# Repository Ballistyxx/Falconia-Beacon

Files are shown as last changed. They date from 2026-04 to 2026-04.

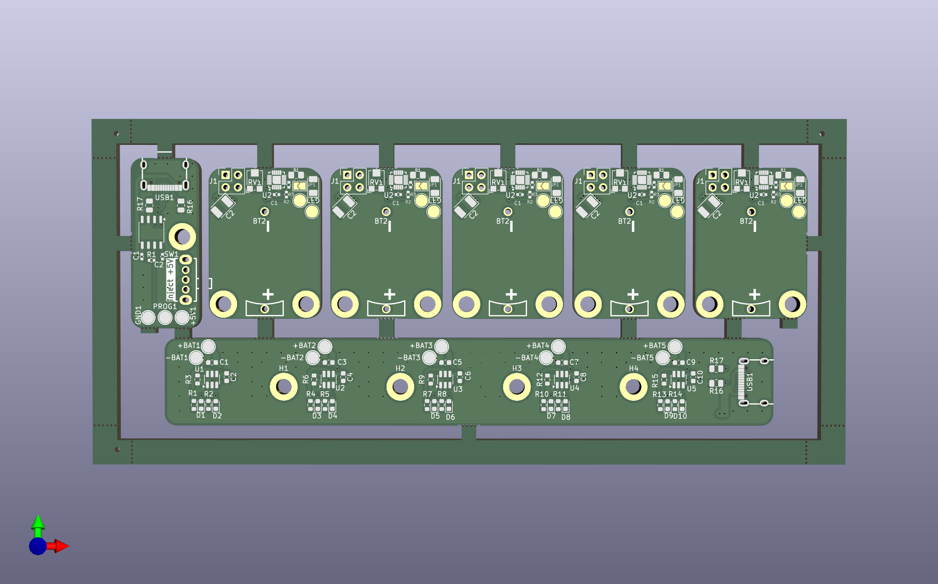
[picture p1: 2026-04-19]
PCB/Datasheets/Panel.png

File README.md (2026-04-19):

# Falconia Beacon

Falconia Beacon is an ATTINY816-based, CR2032-powered LED beacon board used to make the Falconia rover visible to the SMCS Pi-in-the-sky satellite.

## What It Does

- Blinks onboard LEDs so the satellite can detect the rover location.
- Uses a potentiometer to enable or disable the blinking program.
- Supports I2C control at address `0x42`.

## Project Layout

- `PCB/`  
  Hardware design and manufacturing assets:
  - KiCad schematic and PCB files
  - 3D models and custom footprints/symbol libraries
  - Panelization and production outputs

- `src/`  
  Firmware source flashed to the board by default:
  - Main beacon firmware and related examples
  - Build files (Makefile)

## Hardware Summary

- MCU: Microchip ATTINY816
- Power: CR2032 coin cell
- Interface: I2C (address `0x42`)
- User control: Potentiometer (blink program on/off)

## Firmware

The default board firmware lives in `src/` and is intended to be the code programmed onto production boards unless otherwise noted.

Typical workflow:

1. Build firmware from the `src/` directory.
2. Flash using your ATTINY816 programming setup.
3. Validate LED blink behavior and I2C response at address `0x42`.

## Notes

- Hardware and firmware are versioned together in this repository.
- For board-level updates, start in `PCB/`.
- For behavior/protocol updates, start in `src/`.

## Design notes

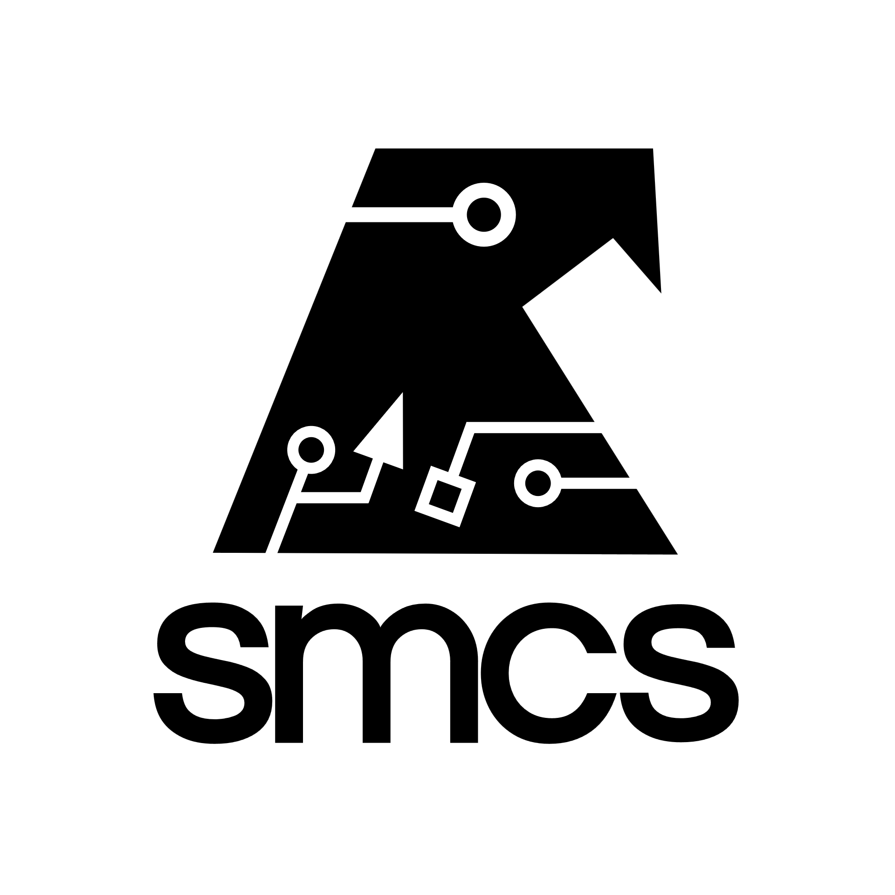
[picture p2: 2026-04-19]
PCB/SMCS.png

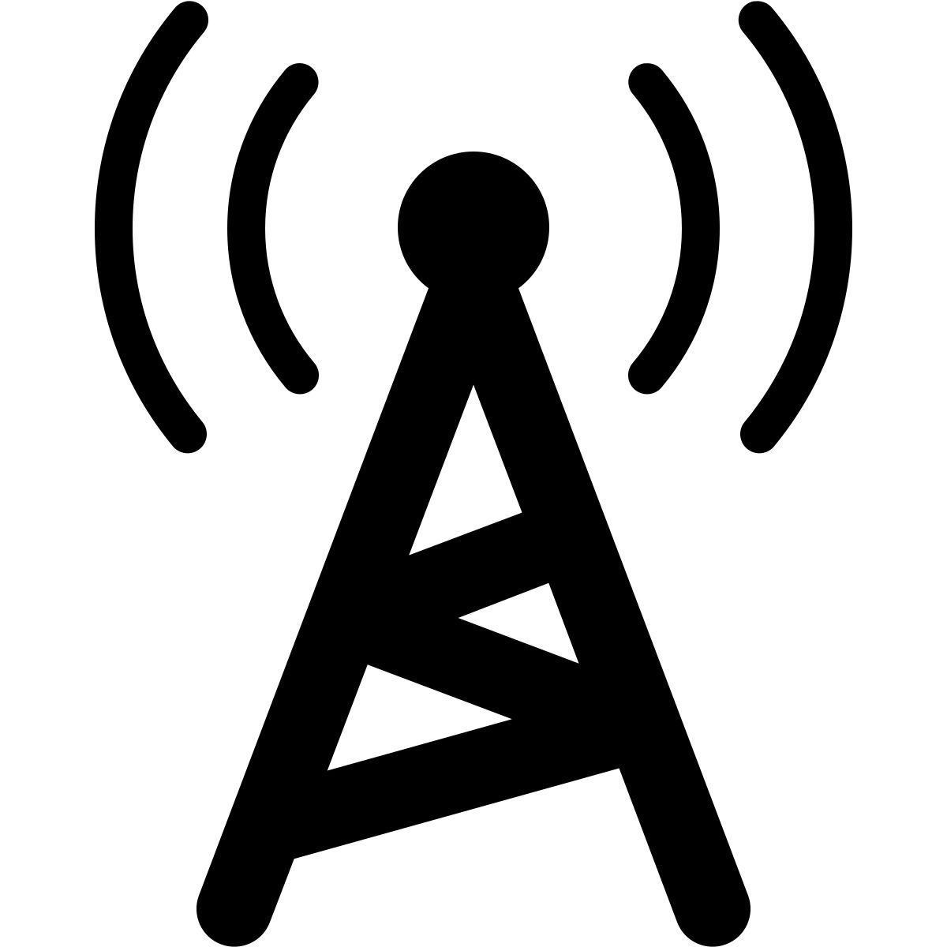
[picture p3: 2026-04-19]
PCB/radio-tower.jpg

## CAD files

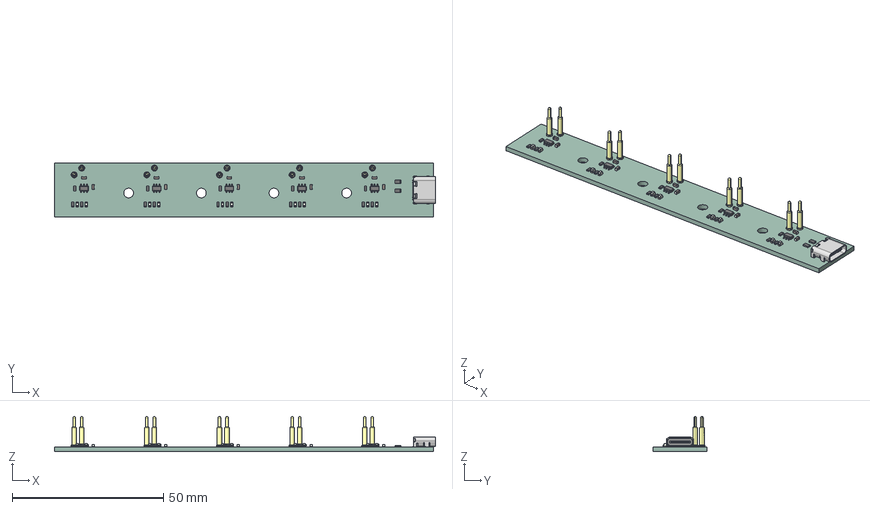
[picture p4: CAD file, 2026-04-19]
PCB/Charger/charger.step
125.9 x 18.0 x 11.6 mm
TSOT-23-6 x 5
SMD-1_BD2.0-H10.0 x 10
LED_0603_1608Metric x 10
R_0603_1608Metric x 15
C_0603_1608Metric x 10
R_0805_2012Metric x 2
USB-C-SMD_TYPE-C-6PIN-2MD-073
charger_PCB

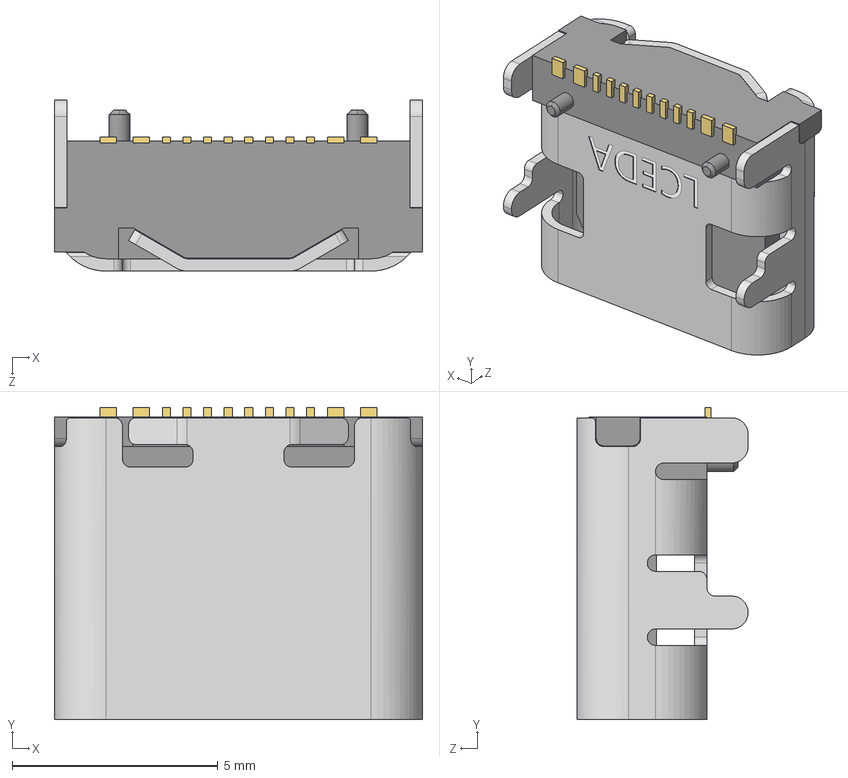
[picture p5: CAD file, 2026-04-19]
PCB/Charger/jlcpcb_lib/3dmodels/USB-C-SMD_TYPE-C-6PIN-2MD-073.step
8.94 x 7.58 x 4.16 mm

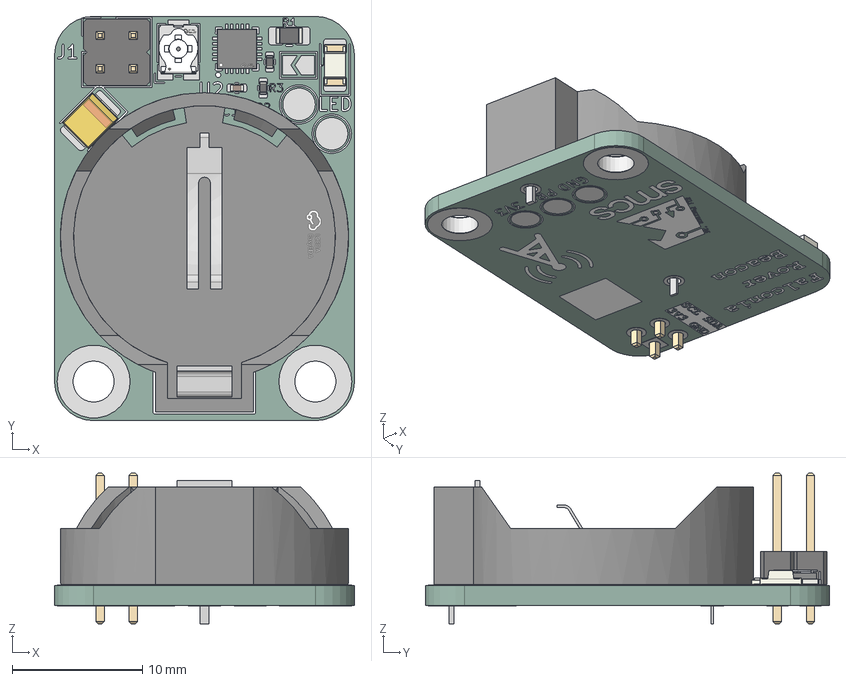
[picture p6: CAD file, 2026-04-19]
PCB/Falconia-Beacon/Falconia-Beacon.step
23.0 x 31.0 x 11.5 mm
CP_EIA-3528-21_Kemet-B
R_0805_2012Metric
UQFN-20_L3.0-W3.0-P0.40-BL-EP1.7
C_0402_1005Metric
BAT-TH_BS-02-A1AJ010
R_0402_1005Metric x 2
PinHeader_2x02_P2.54mm_Vertical
RES-ADJ-SMD_3P-L3.0-W3.8-P1.75-BR
LED_1206_3216Metric
Falconia-Beacon_pad
Falconia-Beacon_silkscreen x 2
Falconia-Beacon_PCB

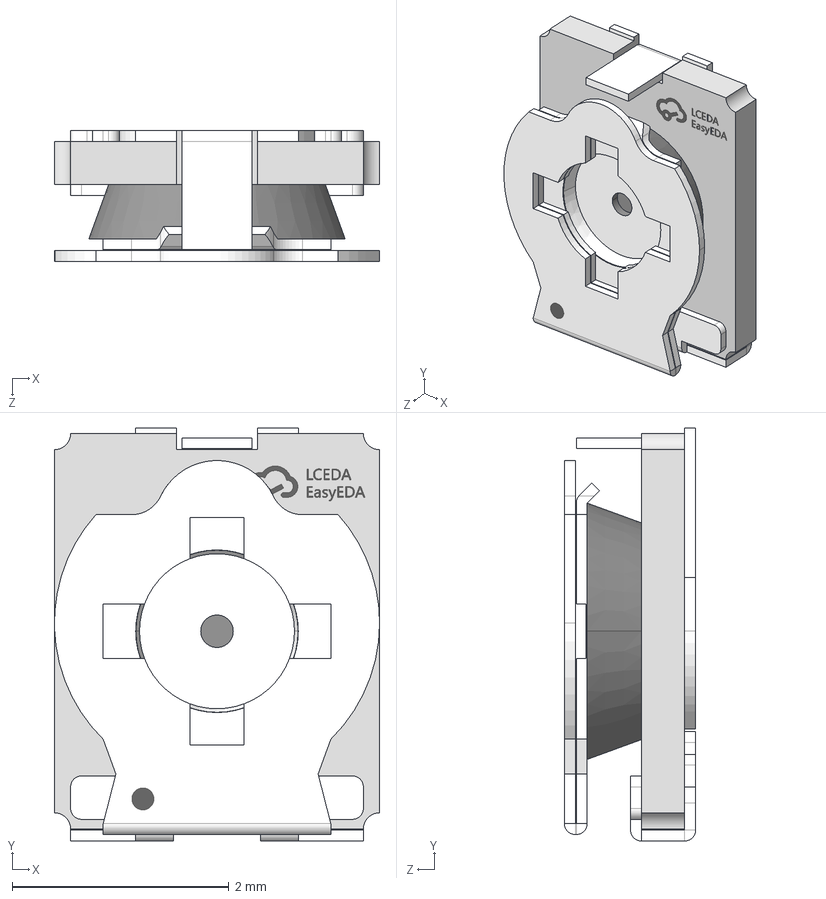
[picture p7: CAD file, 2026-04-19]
PCB/Falconia-Beacon/jlcpcb_lib/3dmodels/RES-ADJ-SMD_3P-L3.0-W3.8-P1.75-BR.step
3.00 x 3.81 x 1.21 mm

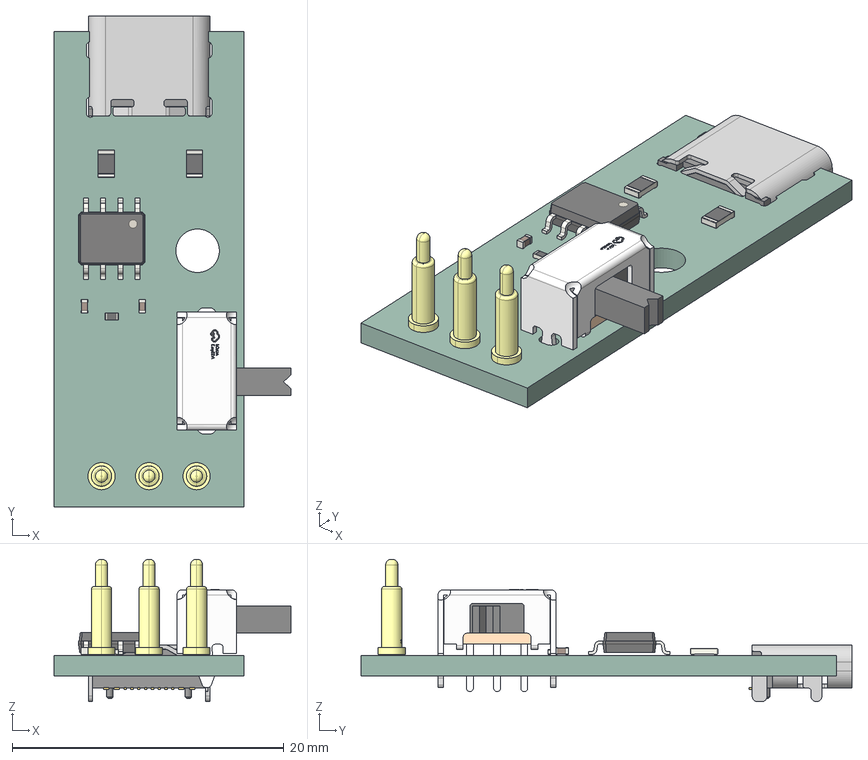
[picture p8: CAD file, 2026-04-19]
PCB/Programmer/programmer.step
17.5 x 36.1 x 10.5 mm
R_0402_1005Metric
BAT-SMD_BD2.0-2P-2.54PH-7.0H x 3
SW-TH_SK12D07VG3
R_0805_2012Metric x 2
C_0402_1005Metric x 2
JEITA_SOIC-8_3.9x4.9mm_P1.27mm
USB-C-SMD_TYPE-C-6PIN-2MD-073
programmer_PCB

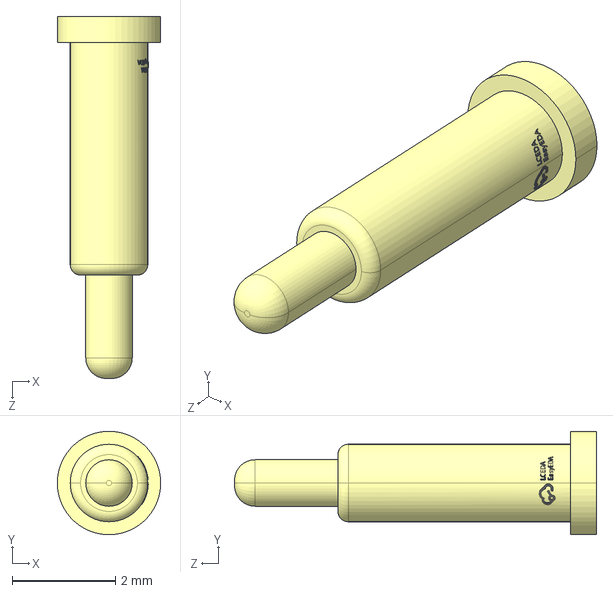
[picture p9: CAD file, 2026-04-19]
PCB/Charger/jlcpcb_lib/3dmodels/BAT-SMD_BD2.0-2P-2.54PH-7.0H.step
2.00 x 2.00 x 7.00 mm

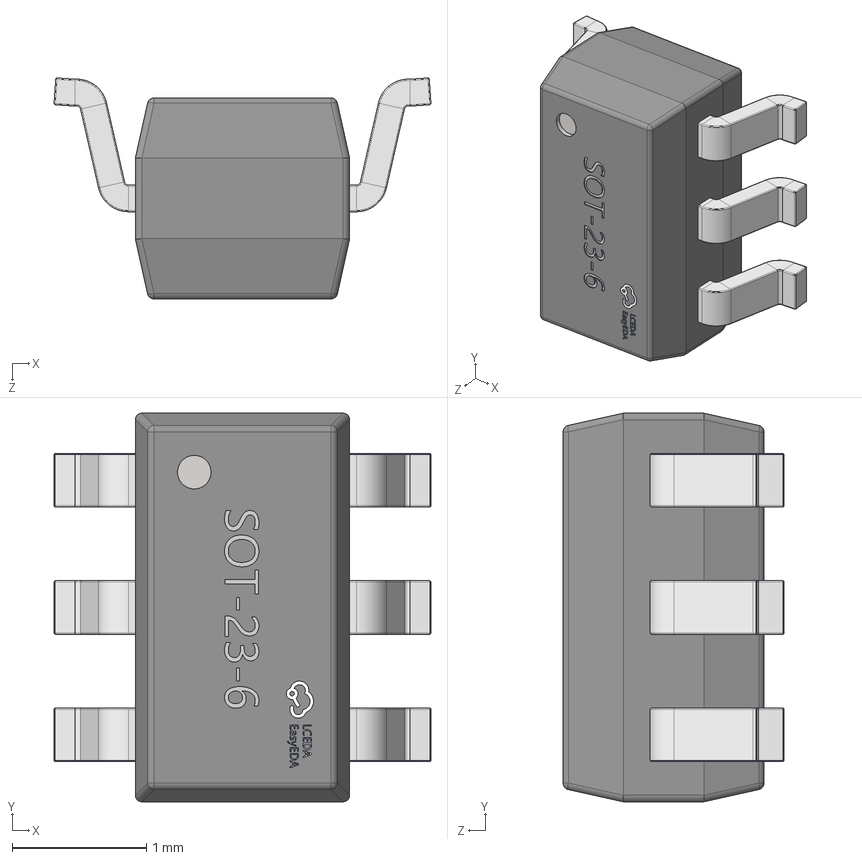
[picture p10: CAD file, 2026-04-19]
PCB/Falconia-Beacon/jlcpcb_lib/3dmodels/SOT-23-6_L2.9-W1.6-P0.95-LS2.8-BL.step
2.81 x 2.90 x 1.65 mm

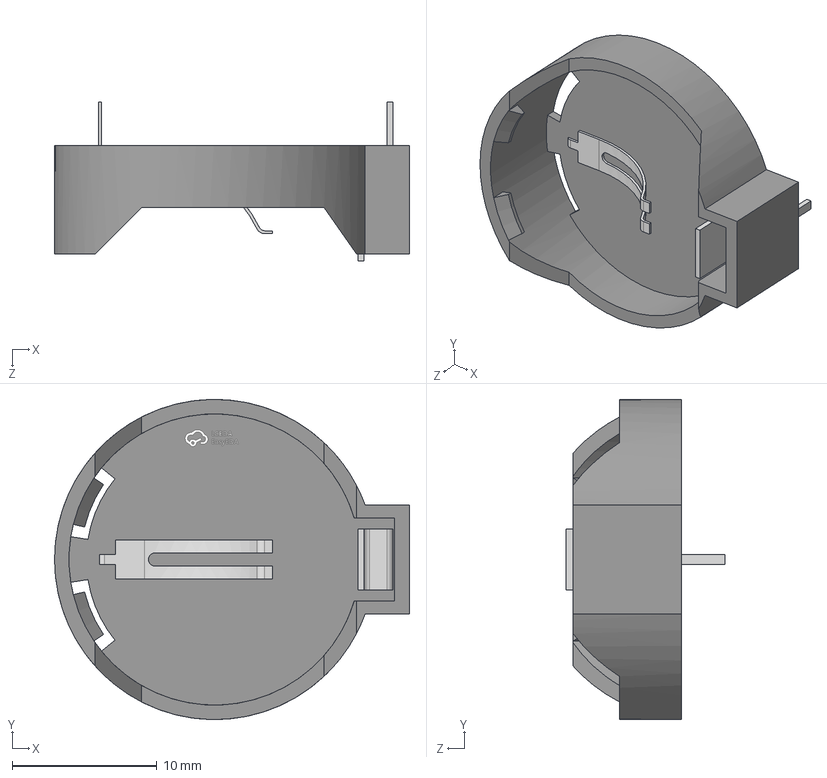
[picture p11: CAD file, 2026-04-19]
PCB/Falconia-Beacon/jlcpcb_lib/3dmodels/BAT-TH_BS-02-A1AJ010.step
24.5 x 22.1 x 11.0 mm

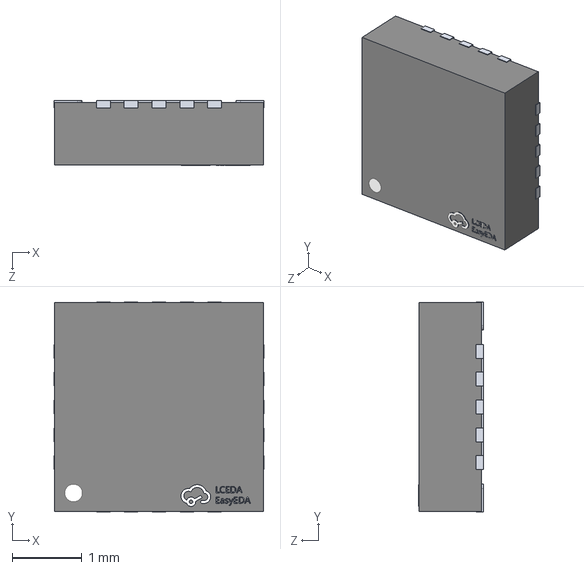
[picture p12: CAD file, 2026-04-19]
PCB/Falconia-Beacon/jlcpcb_lib/3dmodels/UQFN-20_L3.0-W3.0-P0.40-BL-EP1.7.step
3.02 x 3.02 x 0.94 mm

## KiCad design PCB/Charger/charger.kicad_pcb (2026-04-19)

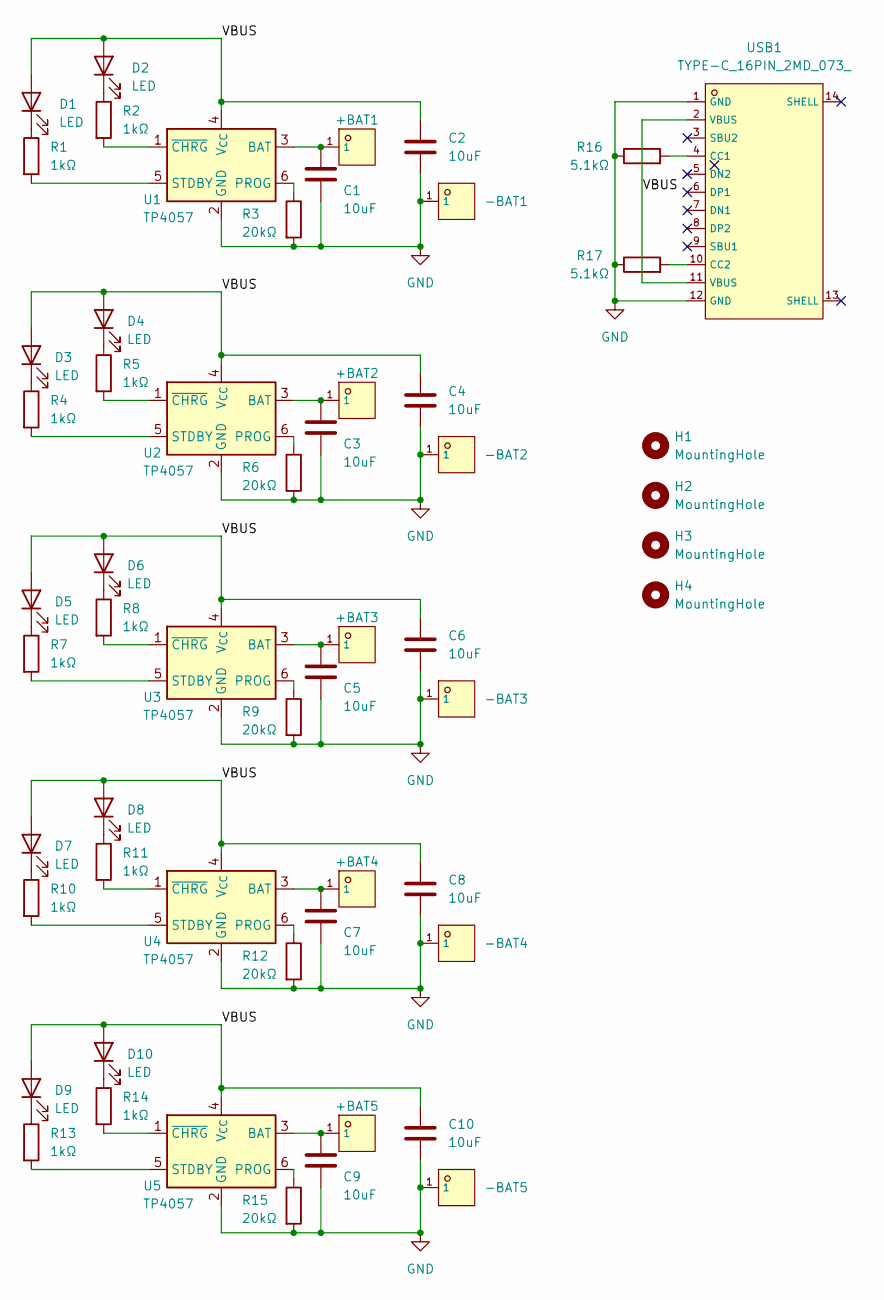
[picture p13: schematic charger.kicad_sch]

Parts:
+BAT1, +BAT2, +BAT3, +BAT4, +BAT5: YTC1P-6030-01; SMD-1_BD2.0-H10.0; LCSC C5221285
-BAT1, -BAT2, -BAT3, -BAT4, -BAT5: YTC1P-6030-01; SMD-1_BD2.0-H10.0; LCSC C5221285
C1, C2, C3, C4, C5, C6, C7, C8, C9, C10: 10uF; C_0603_1608Metric
D1, D2, D3, D4, D5, D6, D7, D8, D9, D10: LED; LED_0603_1608Metric
H1, H2, H3, H4: MountingHole; MountingHole_3.2mm_M3_ISO7380_Pad
R1, R2, R4, R5, R7, R8, R10, R11, R13, R14: 1kΩ; R_0603_1608Metric
R3, R6, R9, R12, R15: 20kΩ; R_0603_1608Metric
R16, R17: 5.1kΩ; R_0805_2012Metric
U1, U2, U3, U4, U5: TP4057; TSOT-23-6
USB1: TYPE-C_16PIN_2MD_073_; USB-C-SMD_TYPE-C-6PIN-2MD-073; LCSC C2765186

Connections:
/VBUS: C2.1, C4.1, C6.1, C8.1, C10.1, D1.2 (A), D2.2 (A), D3.2 (A), D4.2 (A), D5.2 (A), D6.2 (A), D7.2 (A), D8.2 (A), D9.2 (A), D10.2 (A), U1.4 (V_{CC}), U2.4 (V_{CC}), U3.4 (V_{CC}), U4.4 (V_{CC}), U5.4 (V_{CC}), USB1.2 (VBUS), USB1.11 (VBUS)
GND: -BAT1.1, -BAT2.1, -BAT3.1, -BAT4.1, -BAT5.1, C1.2, C2.2, C3.2, C4.2, C5.2, C6.2, C7.2, C8.2, C9.2, C10.2, R3.2, R6.2, R9.2, R12.2, R15.2, R16.1, R17.1, U1.2 (GND), U2.2 (GND), U3.2 (GND), U4.2 (GND), U5.2 (GND), USB1.1 (GND), USB1.12 (GND)
unnamed: D1.1 (K), R1.1
unnamed: D2.1 (K), R2.1
unnamed: D3.1 (K), R4.1
unnamed: D4.1 (K), R5.1
unnamed: D5.1 (K), R7.1
unnamed: D6.1 (K), R8.1
unnamed: D7.1 (K), R10.1
unnamed: D8.1 (K), R11.1
unnamed: D9.1 (K), R13.1
unnamed: D10.1 (K), R14.1
unnamed: +BAT1.1, C1.1, U1.3 (BAT)
unnamed: R3.1, U1.6 (PROG)
unnamed: R1.2, U1.5 (STDBY)
unnamed: R2.2, U1.1 (~CHRG)
unnamed: +BAT2.1, C3.1, U2.3 (BAT)
unnamed: R6.1, U2.6 (PROG)
unnamed: R4.2, U2.5 (STDBY)
unnamed: R5.2, U2.1 (~CHRG)
unnamed: +BAT3.1, C5.1, U3.3 (BAT)
unnamed: R9.1, U3.6 (PROG)
unnamed: R7.2, U3.5 (STDBY)
unnamed: R8.2, U3.1 (~CHRG)
unnamed: +BAT4.1, C7.1, U4.3 (BAT)
unnamed: R12.1, U4.6 (PROG)
unnamed: R10.2, U4.5 (STDBY)
unnamed: R11.2, U4.1 (~CHRG)
unnamed: +BAT5.1, C9.1, U5.3 (BAT)
unnamed: R15.1, U5.6 (PROG)
unnamed: R13.2, U5.5 (STDBY)
unnamed: R14.2, U5.1 (~CHRG)
unnamed: R16.2, USB1.4 (CC1)
unnamed: R17.2, USB1.10 (CC2)

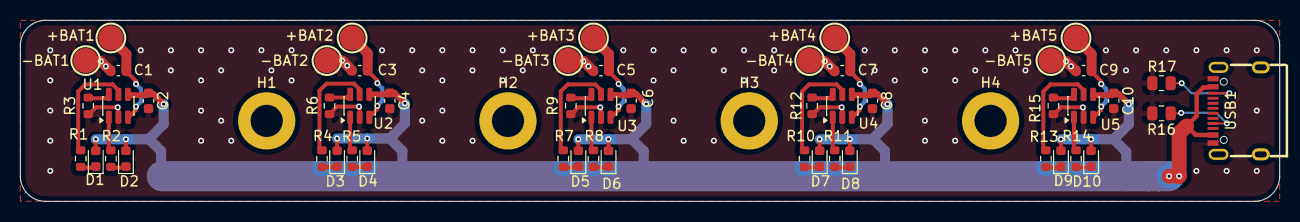
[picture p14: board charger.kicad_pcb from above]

Board: 2 copper layers, 125.2 x 18.0 mm, 57 parts (0 on the bottom side), 34 nets.

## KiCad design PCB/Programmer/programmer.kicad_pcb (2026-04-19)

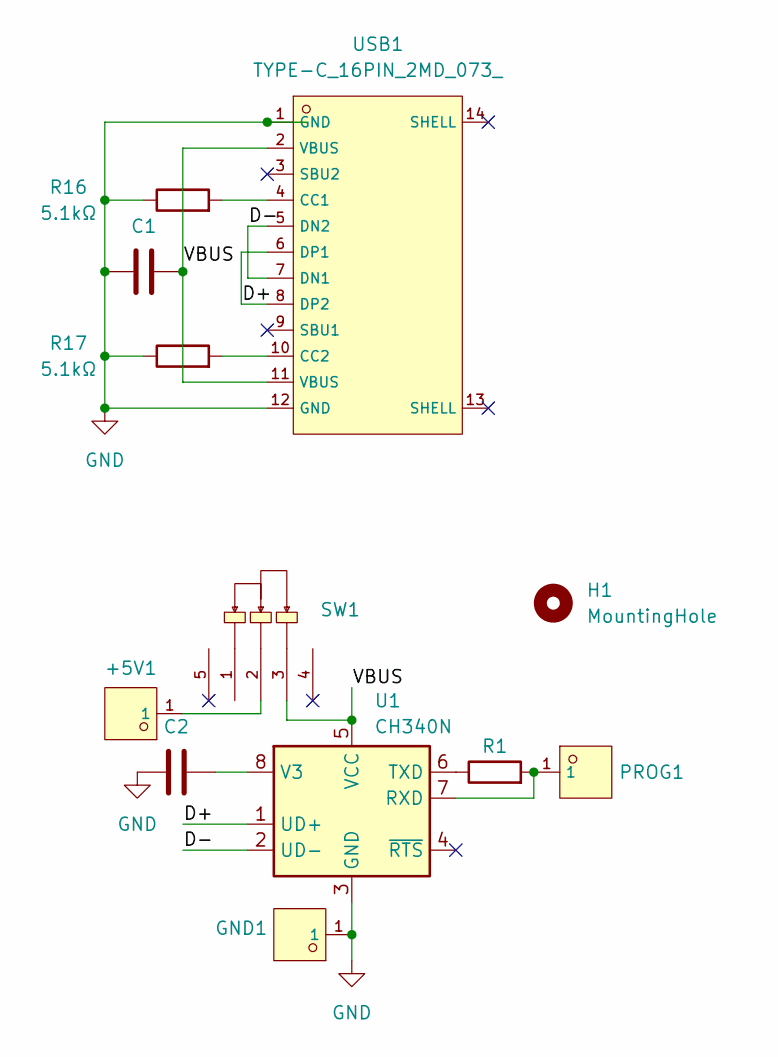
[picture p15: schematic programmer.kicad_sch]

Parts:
+5V1: YTC1P-6030-01; SMD-1_BD2.0-H10.0; LCSC C5221285
C1, C2: 100nF; C_0402_1005Metric
GND1: YTC1P-6030-01; SMD-1_BD2.0-H10.0; LCSC C5221285
H1: MountingHole; MountingHole_3.2mm_M3_DIN965_Pad
PROG1: YTC1P-6030-01; SMD-1_BD2.0-H10.0; LCSC C5221285
R1: 10kΩ; R_0402_1005Metric
R16, R17: 5.1kΩ; R_0805_2012Metric
SW1: SK12D07VG3_C431547; SW-TH_SK12D07VG3; LCSC C431547
U1: CH340N; JEITA_SOIC-8_3.9x4.9mm_P1.27mm
USB1: TYPE-C_16PIN_2MD_073_; USB-C-SMD_TYPE-C-6PIN-2MD-073; LCSC C2765186

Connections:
/D+: U1.1 (UD+), USB1.6 (DP1), USB1.8 (DP2)
/D-: U1.2 (UD-), USB1.5 (DN2), USB1.7 (DN1)
/VBUS: C1.2, SW1.3, U1.5 (VCC), USB1.2 (VBUS), USB1.11 (VBUS)
GND: C1.1, C2.1, GND1.1, R16.1, R17.1, U1.3 (GND), USB1.1 (GND), USB1.12 (GND)
unnamed: +5V1.1, SW1.2
unnamed: PROG1.1, R1.2, U1.7 (RXD)
unnamed: R1.1, U1.6 (TXD)
unnamed: C2.2, U1.8 (V3)
unnamed: R16.2, USB1.4 (CC1)
unnamed: R17.2, USB1.10 (CC2)

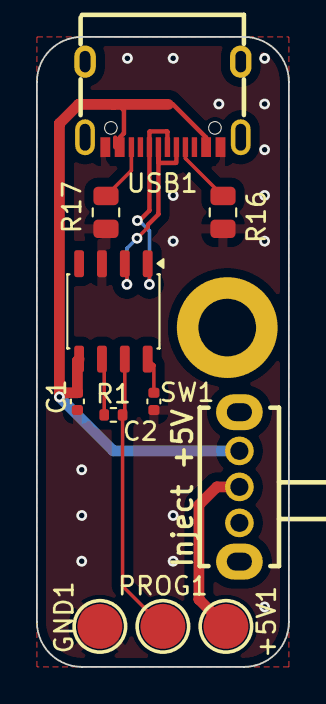
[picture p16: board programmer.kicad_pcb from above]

Board: 2 copper layers, 14.0 x 35.0 mm, 12 parts (0 on the bottom side), 10 nets.

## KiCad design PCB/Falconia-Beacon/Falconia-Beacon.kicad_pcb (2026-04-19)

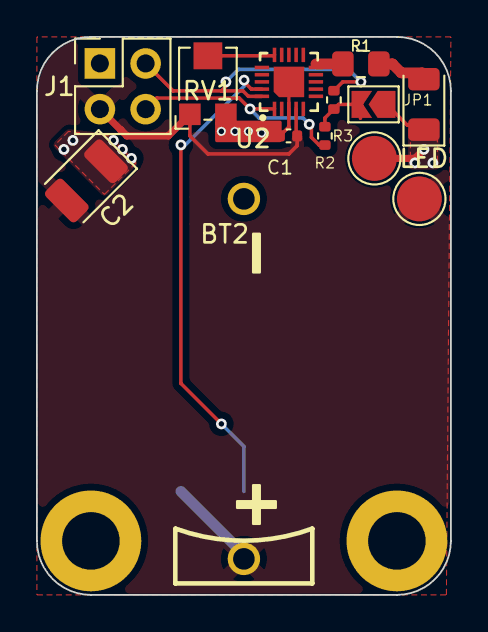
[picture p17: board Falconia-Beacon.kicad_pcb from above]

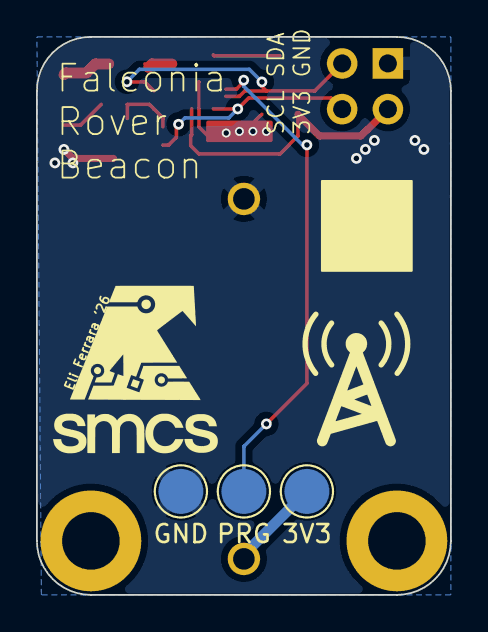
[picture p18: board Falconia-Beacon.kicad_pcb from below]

Board: 2 copper layers, 23.0 x 31.0 mm, 14 parts (3 on the bottom side), 9 nets.

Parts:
3V3: TestPoint_Pad_D2.5mm
BT2: BS-02-A1AJ010; BAT-TH_BS-02-A1AJ010
C1: 100nF; C_0402_1005Metric
C2: 100uF; CP_EIA-3528-21_Kemet-B
GND: TestPoint_Pad_D2.5mm
J1: Conn_02x02_Odd_Even; PinHeader_2x02_P2.54mm_Vertical
JP1: SolderJumper_2_Open; SolderJumper-2_P1.3mm_Open_TrianglePad1.0x1.5mm
LED: LED; LED_1206_3216Metric
PRG: TestPoint_Pad_D2.5mm
R1: 33Ω; R_0805_2012Metric_Pad1.20x1.40mm_HandSolder
R2, R3: 2.2kΩ; R_0402_1005Metric
RV1: R_Potentiometer; Potentiometer_Bourns_TC33X_Vertical
U2: ATTINY816-MNR; UQFN-20_L3.0-W3.0-P0.40-BL-EP1.7

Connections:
+3.3V: 3V3.1, BT2.2, C1.2, C2.2, J1.3, RV1.1, U2.4 (VDD)
/SCL: J1.4, R2.2, U2.1 (PA2)
/SDA: J1.2, R3.2, U2.20 (PA1)
/UPDI: PRG.1, U2.19 (PA0/RESET#/UPDI)
GND: BT2.1, C1.1, C2.1, GND.1, J1.1, JP1.1 (A), LED.1 (K), RV1.3, U2.3 (GND), U2.21 (GND)
unnamed: JP1.2 (B), R2.1, R3.1
unnamed: LED.2 (A), R1.1
unnamed: R1.2, U2.10 (PB4)
unnamed: RV1.2, U2.15 (PC0)

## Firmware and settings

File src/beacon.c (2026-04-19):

/*
 * beacon.c — ATtiny816 coin-cell LED blinker
 *
 * Pot on PC0 (digital input only — no ADC channel on PORTC).
 *   Pot turned down (PC0 low)  → 1 s on / 1 s off blink
 *   Pot turned up   (PC0 high) → LED steady on
 *
 * LED on PB4, active-high.
 * Clock: 3.333 MHz (20 MHz / 6, default fuse)
 */

#include <avr/io.h>
#include <avr/interrupt.h>
#include <avr/sleep.h>

/* ── Timer (TCA0 overflow for blink timing) ──────────────── */

static volatile uint8_t tick_flag;

ISR(TCA0_OVF_vect)
{
    TCA0.SINGLE.INTFLAGS = TCA_SINGLE_OVF_bm;
    tick_flag = 1;
}

static void timer_init(void)
{
    /*
     * ~10 ms tick: 3 333 333 / 64 = 52 083 Hz → PER = 520 → 9.98 ms
     */
    TCA0.SINGLE.PER     = 520;
    TCA0.SINGLE.INTCTRL = TCA_SINGLE_OVF_bm;
    TCA0.SINGLE.CTRLA   = TCA_SINGLE_CLKSEL_DIV64_gc
                         | TCA_SINGLE_ENABLE_bm;
}

/* ── Main ────────────────────────────────────────────────── */

int main(void)
{
    /* LED pin output, start off */
    PORTB.DIRSET = PIN4_bm;
    PORTB.OUTCLR = PIN4_bm;

    /* PC0 as input with internal pull-up enabled */
    PORTC.DIRCLR  = PIN0_bm;
    PORTC.PIN0CTRL = PORT_PULLUPEN_bm;

    timer_init();
    sei();

    set_sleep_mode(SLEEP_MODE_IDLE);

    uint16_t tick_count  = 0;
    uint8_t  led_on      = 0;
    const uint16_t half_period = 100;  /* 100 × 10 ms = 1 s */

    for (;;) {
        sleep_mode();

        if (!tick_flag)
            continue;
        tick_flag = 0;

        uint8_t pot_high = (PORTC.IN & PIN0_bm);

        if (!pot_high) {
            /* Pot turned down → steady off */
            PORTB.OUTCLR = PIN4_bm;
            led_on     = 0;
            tick_count = 0;
        } else {
            /* Pot turned up → blink */
            if (++tick_count >= half_period) {
                tick_count = 0;
                led_on ^= 1;
                if (led_on)
                    PORTB.OUTSET = PIN4_bm;
                else
                    PORTB.OUTCLR = PIN4_bm;
            }
        }
    }
}
